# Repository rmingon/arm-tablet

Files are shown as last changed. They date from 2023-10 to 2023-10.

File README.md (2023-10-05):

# ARM TABLET project with 480x800 screen connected with FSMC bus

## OLD VERSION VIDEO -> [VIDEO](https://www.youtube.com/shorts/6iCVGylVFGs)

### this tablet work with 10Ah lipo battery and STM32F407 mcu

## NEW VERSION BASED ON KICAD

### 3D
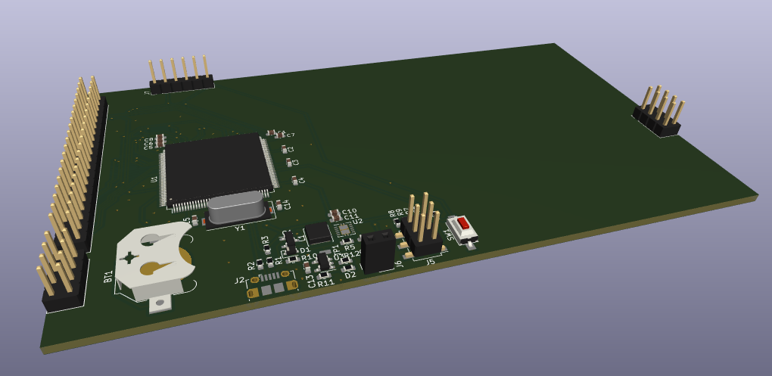
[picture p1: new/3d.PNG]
3D VIEW


### PCB
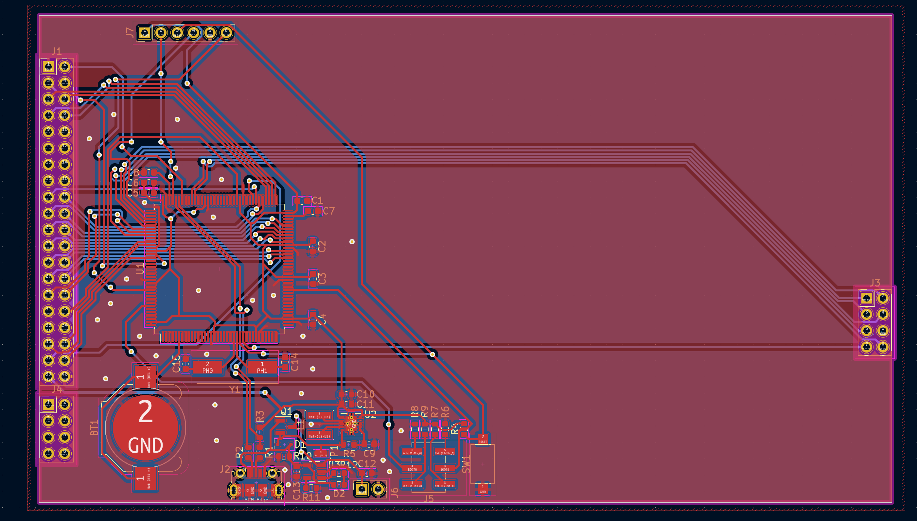
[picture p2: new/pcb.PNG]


### schematic
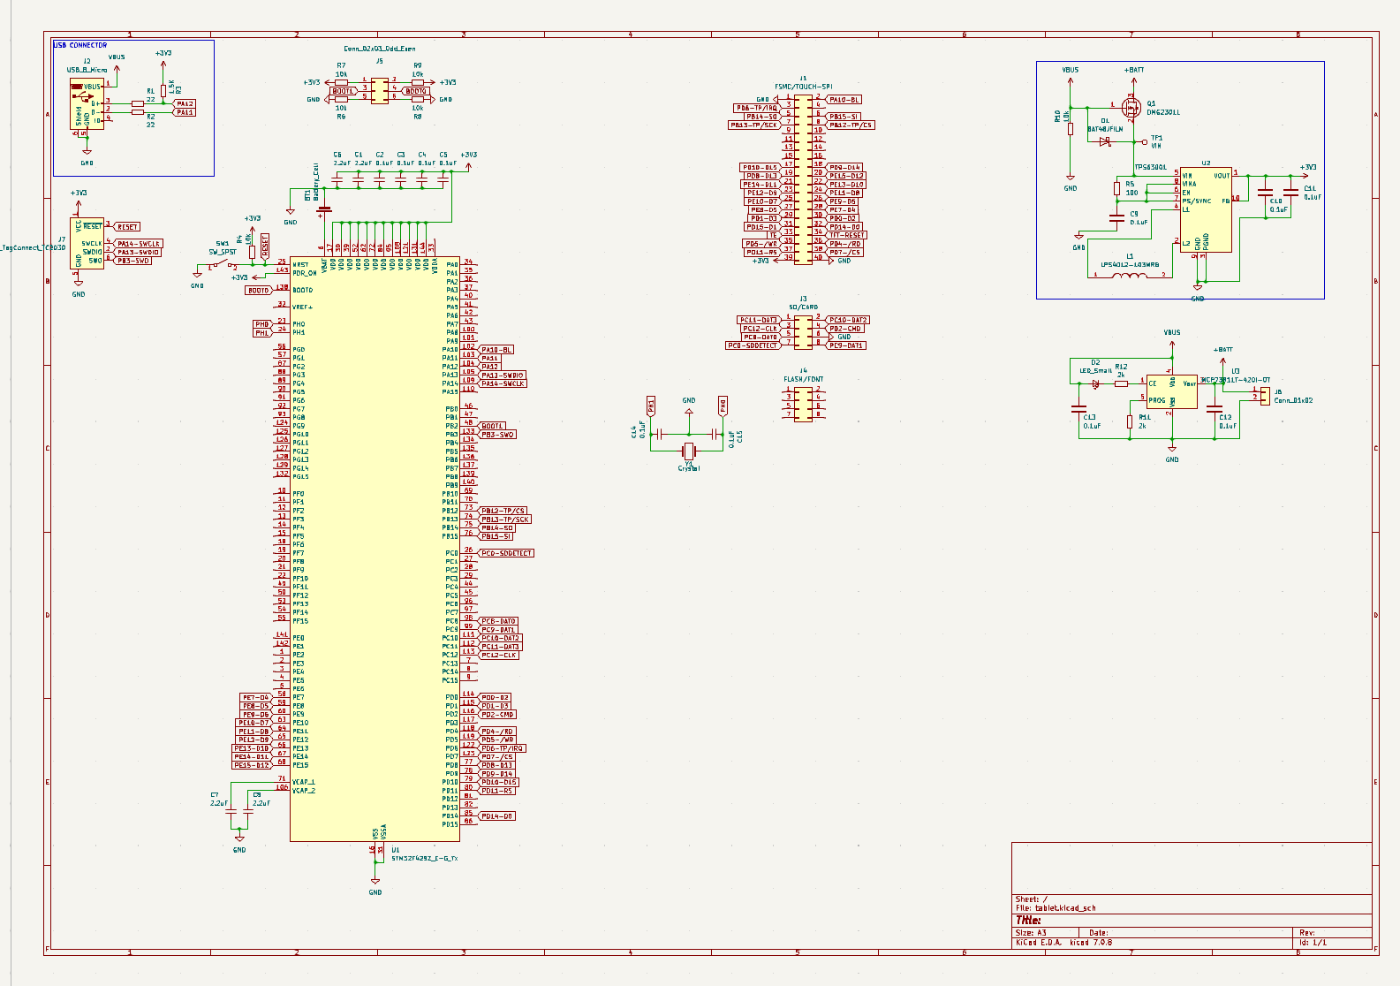
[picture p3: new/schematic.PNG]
SCHEMATIC VIEW


---

## OLD VERSION BASED ON FUSION360

### PCB
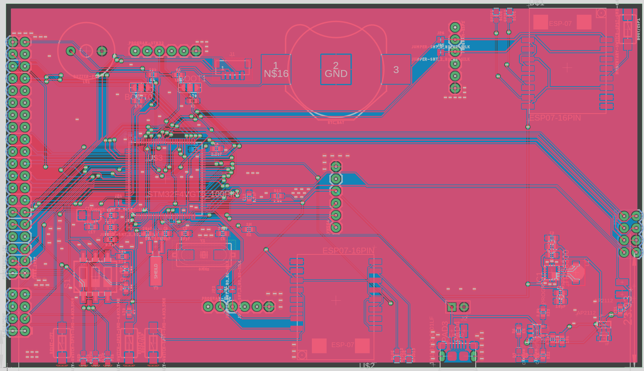
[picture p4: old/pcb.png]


### schematic
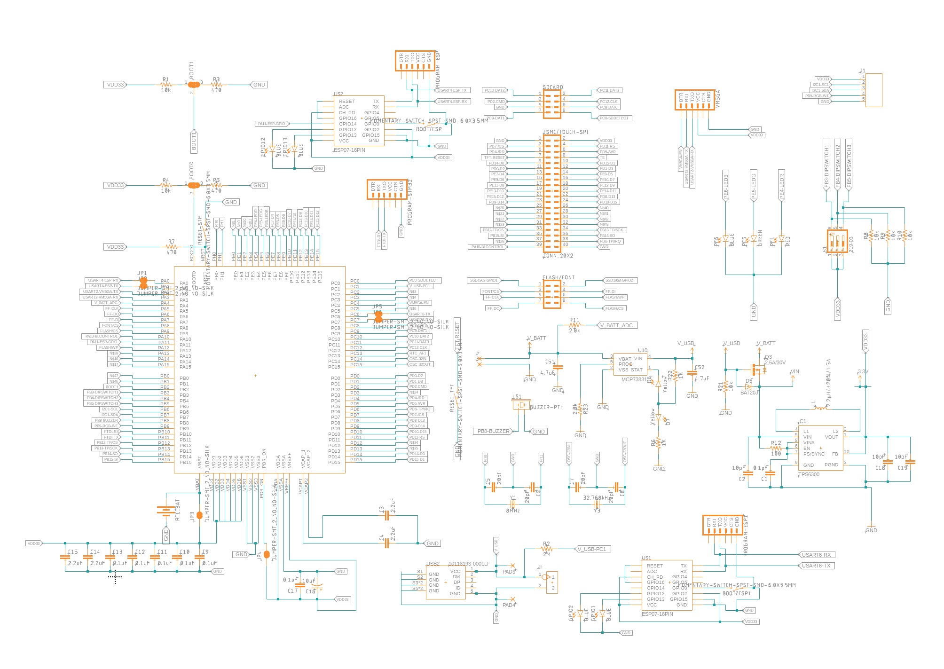
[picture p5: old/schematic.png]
SCHEMATIC VIEW


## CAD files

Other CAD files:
old/tablet.f3z

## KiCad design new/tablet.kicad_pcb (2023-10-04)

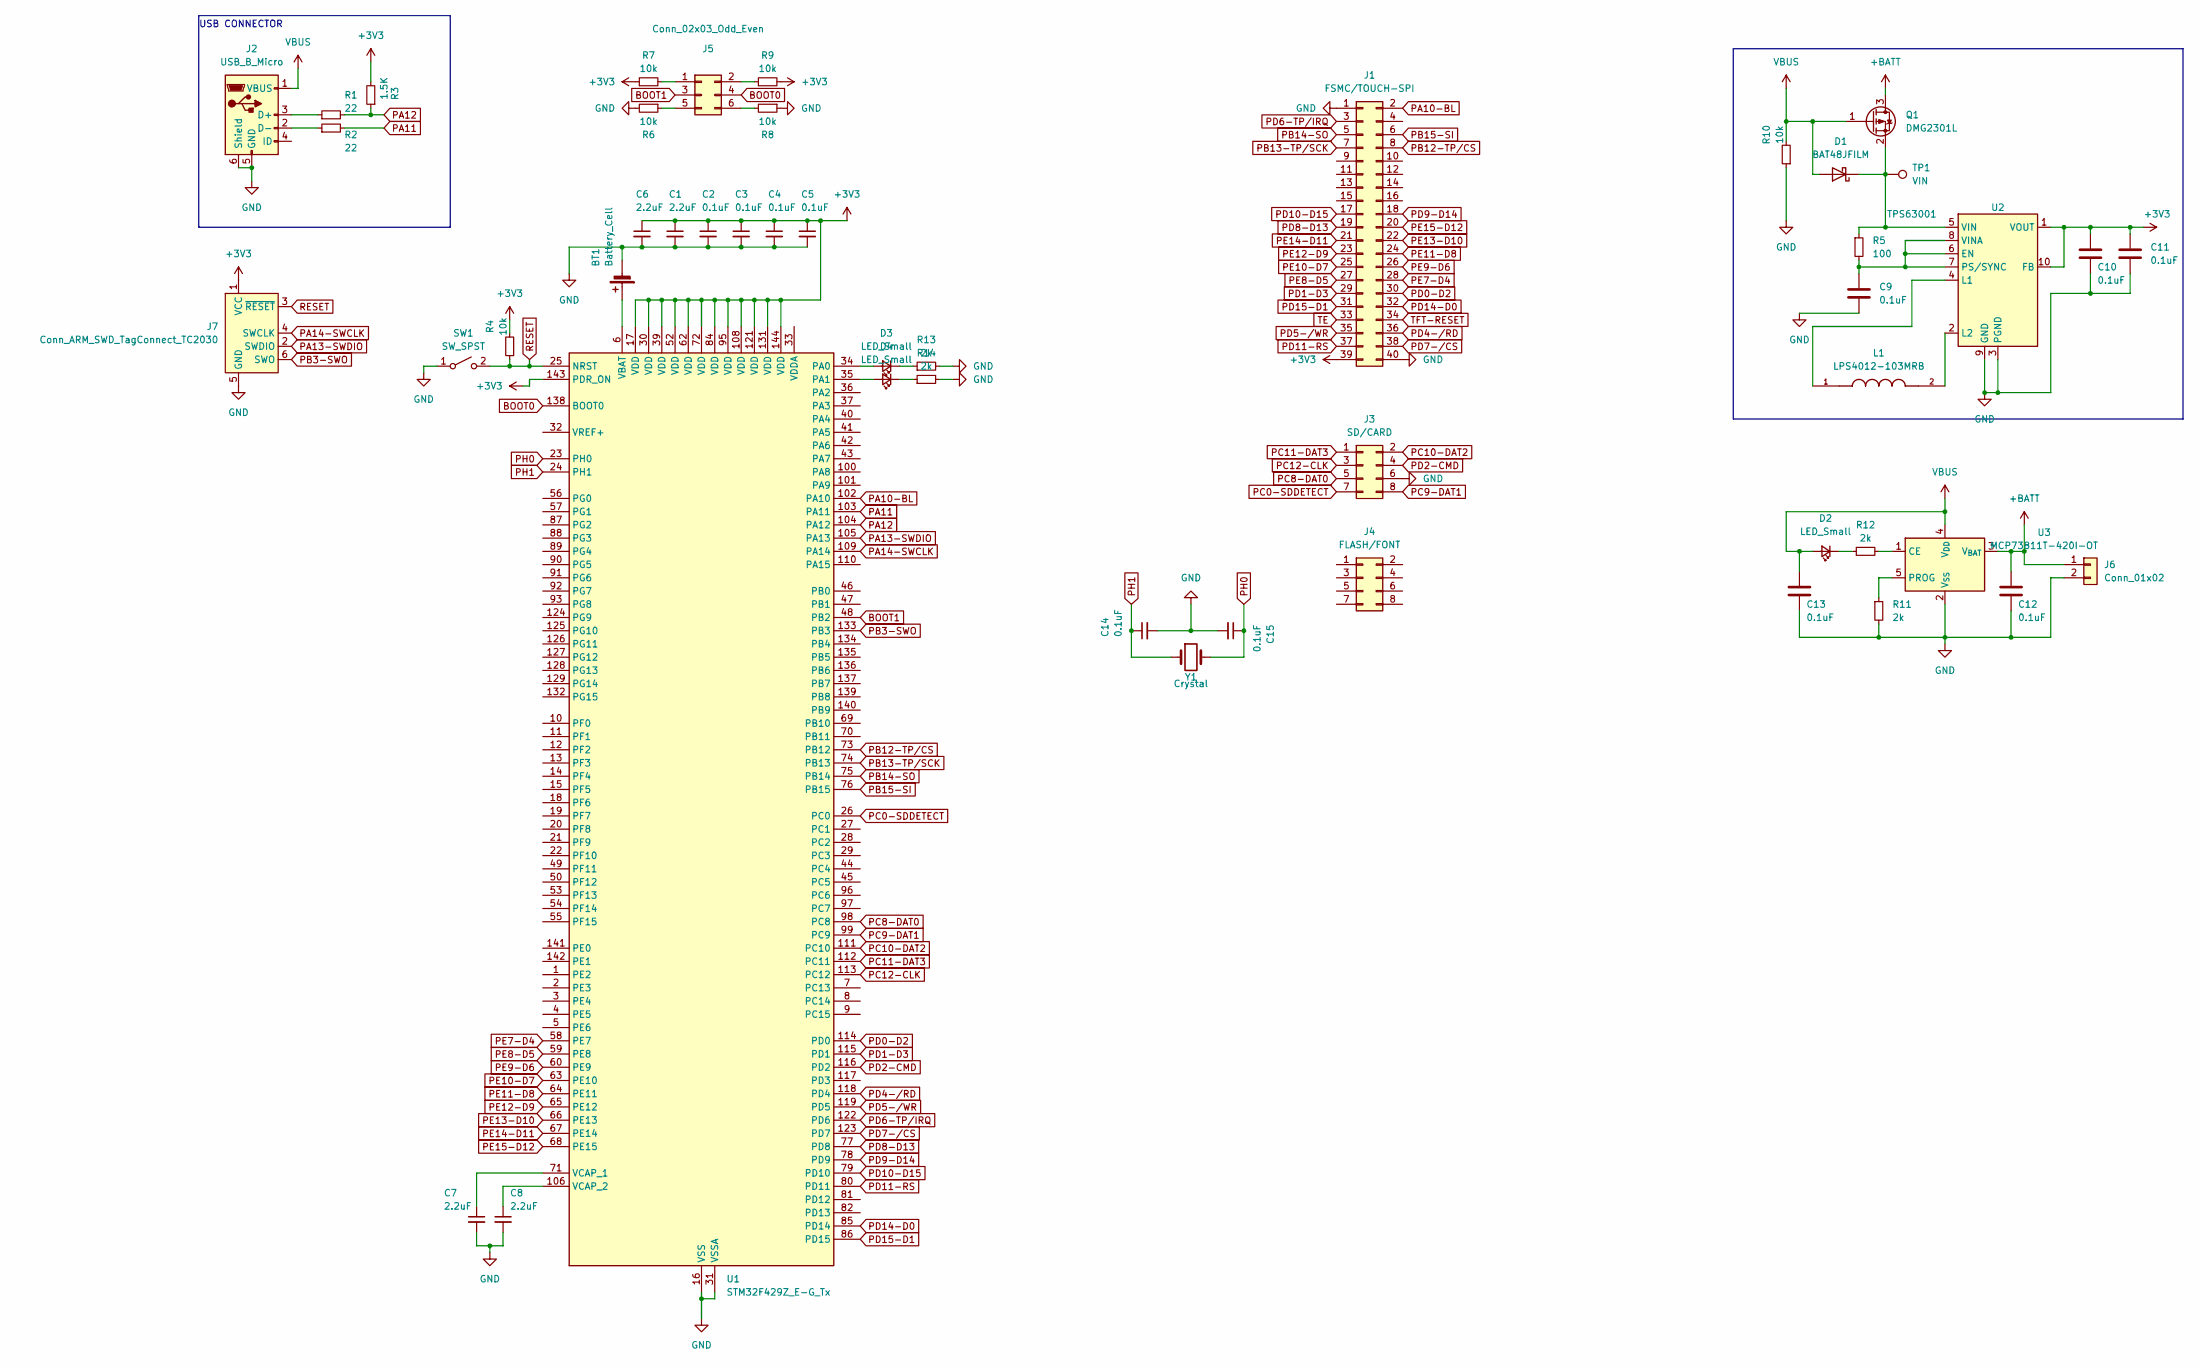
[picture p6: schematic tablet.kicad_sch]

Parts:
BT1: Battery_Cell; BatteryHolder_Keystone_3000_1x12mm
C1, C6, C7, C8: 2.2uF; C_0603_1608Metric
C2, C3, C4, C5, C9, C10, C11, C12, C13, C14, C15: 0.1uF; C_0603_1608Metric
D1: BAT48JFILM; D_SOD-323
D2, D3, D4: LED_Small; R_0603_1608Metric
J1: FSMC/TOUCH-SPI; PinHeader_2x20_P2.54mm_Vertical
J2: USB_B_Micro; USB_Micro-B_Molex-105017-0001
J3: SD/CARD; PinHeader_2x04_P2.54mm_Vertical
J4: FLASH/FONT; PinHeader_2x04_P2.54mm_Vertical
J5: Conn_02x03_Odd_Even; PinHeader_2x03_P2.54mm_Vertical_SMD
J6: Conn_01x02; PinSocket_1x02_P2.54mm_Vertical
J7: Conn_ARM_SWD_TagConnect_TC2030; PinHeader_1x06_P2.54mm_Vertical
L1: LPS4012-103MRB; L_Sunlord_SWPA4012S; PARTREV 08/01/13
Q1: DMG2301L; SOT-23
R1, R2: 22; R_0603_1608Metric
R3: 1.5K; R_0603_1608Metric
R4, R6, R7, R8, R9, R10: 10k; R_0603_1608Metric
R5: 100; R_0603_1608Metric
R11, R12, R13, R14: 2k; R_0603_1608Metric
SW1: SW_SPST; SW_SPST_CK_RS282G05A3
TP1: VIN; SolderWirePad_1x01_SMD_1x2mm
U1: STM32F429Z_E-G_Tx; LQFP-144_20x20mm_P0.5mm
U2: TPS63001; Texas_DRC0010J_ThermalVias
U3: MCP73811T-420I-OT; SOT-23-5
Y1: Crystal; Crystal_SMD_HC49-SD

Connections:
+3V3: C1.1, C2.1, C3.1, C4.1, C5.1, C6.1, C10.1, C11.1, J1.39, J7.1 (VCC), R3.2, R4.2, R7.1, R9.2, U1.17 (VDD), U1.30 (VDD), U1.39 (VDD), U1.52 (VDD), U1.62 (VDD), U1.72 (VDD), U1.84 (VDD), U1.95 (VDD), U1.108 (VDD), U1.121 (VDD), U1.131 (VDD), U1.143 (PDR_ON), U1.144 (VDD), U2.1 (VOUT), U2.10 (FB)
+BATT: C12.1, J6.1, Q1.3 (D), U3.3 (V_{BAT})
BOOT0: J5.4, U1.138 (BOOT0)
BOOT1: J5.3, U1.48 (PB2)
GND: BT1.2 (-), C1.2, C2.2, C3.2, C4.2, C5.2, C6.2, C7.2, C8.2, C9.2, C10.2, C11.2, C12.2, C13.2, C14.2, C15.2, J1.1, J1.40, J2.5 (GND), J2.6 (Shield), J3.6, J6.2, J7.5 (GND), R6.2, R8.1, R10.1, R11.2, R13.2, R14.2, SW1.1 (A), U1.16 (VSS), U1.31 (VSSA), U1.38 (VSS), U1.51 (VSS), U1.61 (VSS), U1.83 (VSS), U1.94 (VSS), U1.107 (VSS), U1.120 (VSS), U1.130 (VSS), U2.3 (PGND), U2.9 (GND), U2.11 (PGND), U3.2 (V_{SS})
unnamed: BT1.1 (+), U1.6 (VBAT)
unnamed: D1.1 (K), Q1.2 (S), R5.1, TP1.1, U2.5 (VIN)
unnamed: D2.1 (K), R12.1
unnamed: D3.2 (A), U1.34 (PA0)
unnamed: D3.1 (K), R13.1
unnamed: D4.2 (A), U1.35 (PA1)
unnamed: D4.1 (K), R14.1
unnamed: J2.3 (D+), R1.1
unnamed: J2.2 (D-), R2.1
unnamed: J5.1, R7.2
unnamed: J5.2, R9.1
unnamed: J5.5, R6.1
unnamed: J5.6, R8.2
unnamed: C7.1, U1.71 (VCAP_1)
unnamed: C8.1, U1.106 (VCAP_2)
unnamed: C9.1, R5.2, U2.6 (EN), U2.7 (PS/SYNC), U2.8 (VINA)
unnamed: L1.1, U2.4 (L1)
unnamed: L1.2, U2.2 (L2)
unnamed: R12.2, U3.1 (CE)
unnamed: R11.1, U3.5 (PROG)
PA10-BL: J1.2, U1.102 (PA10)
PA11: R2.2, U1.103 (PA11)
PA12: R1.2, R3.1, U1.104 (PA12)
PA13-SWDIO: J7.2 (SWDIO), U1.105 (PA13)
PA14-SWCLK: J7.4 (SWCLK), U1.109 (PA14)
PB3-SWO: J7.6 (SWO), U1.133 (PB3)
PB12-TP/CS: J1.8, U1.73 (PB12)
PB13-TP/SCK: J1.7, U1.74 (PB13)
PB14-SO: J1.5, U1.75 (PB14)
PB15-SI: J1.6, U1.76 (PB15)
PC0-SDDETECT: J3.7, U1.26 (PC0)
PC8-DAT0: J3.5, U1.98 (PC8)
PC9-DAT1: J3.8, U1.99 (PC9)
PC10-DAT2: J3.2, U1.111 (PC10)
PC11-DAT3: J3.1, U1.112 (PC11)
PC12-CLK: J3.3, U1.113 (PC12)
PD0-D2: J1.30, U1.114 (PD0)
PD1-D3: J1.29, U1.115 (PD1)
PD2-CMD: J3.4, U1.116 (PD2)
PD4-/RD: J1.36, U1.118 (PD4)
PD5-/WR: J1.35, U1.119 (PD5)
PD6-TP/IRQ: J1.3, U1.122 (PD6)
PD7-/CS: J1.38, U1.123 (PD7)
PD8-D13: J1.19, U1.77 (PD8)
PD9-D14: J1.18, U1.78 (PD9)
PD10-D15: J1.17, U1.79 (PD10)
PD11-RS: J1.37, U1.80 (PD11)
PD14-D0: J1.32, U1.85 (PD14)
PD15-D1: J1.31, U1.86 (PD15)
PE7-D4: J1.28, U1.58 (PE7)
PE8-D5: J1.27, U1.59 (PE8)
PE9-D6: J1.26, U1.60 (PE9)
PE10-D7: J1.25, U1.63 (PE10)
PE11-D8: J1.24, U1.64 (PE11)
PE12-D9: J1.23, U1.65 (PE12)
PE13-D10: J1.22, U1.66 (PE13)
PE14-D11: J1.21, U1.67 (PE14)
PE15-D12: J1.20, U1.68 (PE15)
PH0: C15.1, U1.23 (PH0), Y1.2
PH1: C14.1, U1.24 (PH1), Y1.1
RESET: J7.3 (~RESET), R4.1, SW1.2 (B), U1.25 (NRST)
TE: J1.33
TFT-RESET: J1.34
VBUS: C13.1, D1.2 (A), D2.2 (A), J2.1 (VBUS), Q1.1 (G), R10.2, U3.4 (V_{DD})

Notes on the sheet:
USB CONNECTOR

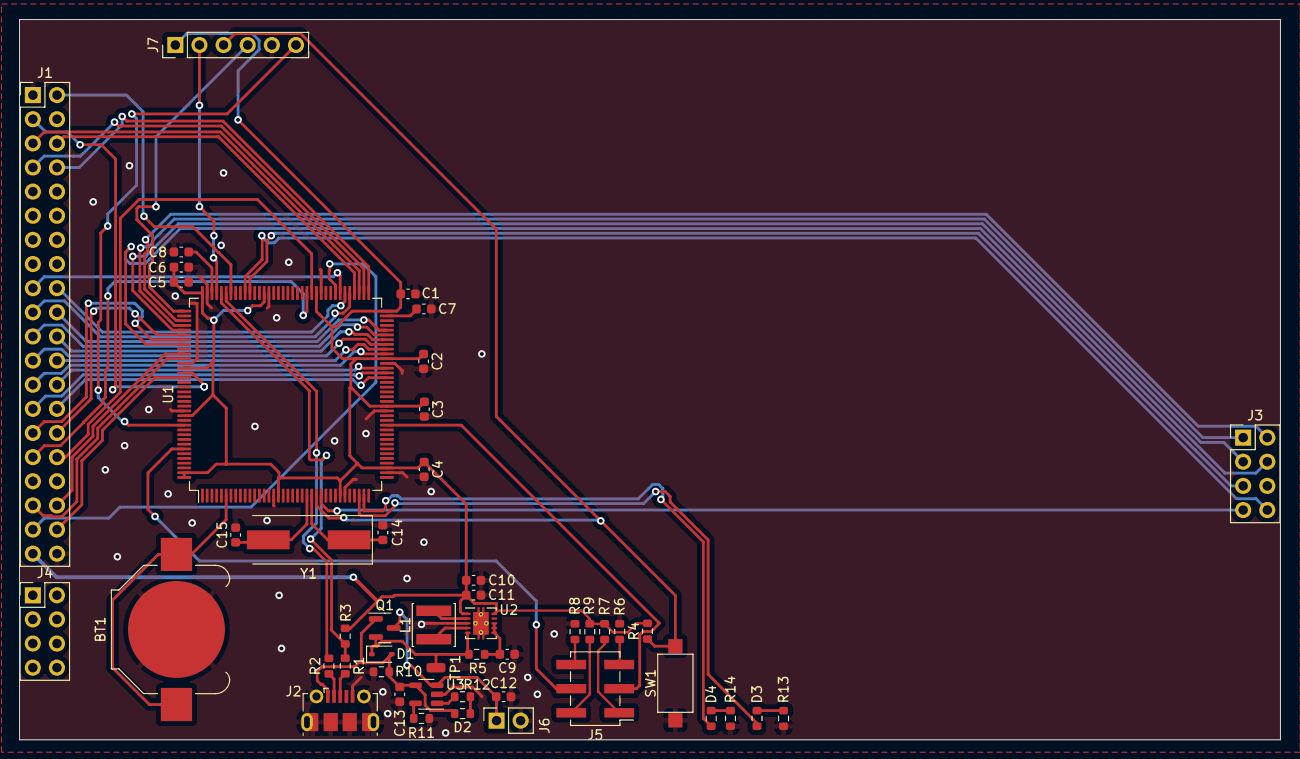
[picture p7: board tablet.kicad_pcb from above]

Board: 2 copper layers, 132.7 x 75.8 mm, 49 parts (0 on the bottom side), 67 nets.

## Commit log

2023-10-01 pcb view
2023-10-01 schematic view
2023-10-04 add fusion file
    [tablet.f3z]
2023-10-04 first commit kicad
    [tablet.kicad_pcb, tablet.kicad_sch]
2023-10-04 add stm32f429 + screen connector
    [tablet.kicad_sch]
2023-10-04 add usb connector
    [tablet.kicad_sch]
2023-10-04 add components
    [tablet.kicad_pcb]
2023-10-04 add footprints
    [tablet.kicad_sch]
2023-10-04 place header on pcb
    [tablet.kicad_pcb, tablet.kicad_sch]
2023-10-04 wiring screen + sdcard
    [tablet.kicad_sch]
2023-10-04 add kicad file
2023-10-04 add TPS63001
    [tablet.kicad_pcb, tablet.kicad_sch]
2023-10-04 add wiring + battery charging
    [tablet.kicad_pcb, tablet.kicad_sch]
2023-10-04 add led
    [tablet.kicad_pcb, tablet.kicad_sch]
2023-10-04 send for production
    [tablet.kicad_pcb, tablet.kicad_sch]
